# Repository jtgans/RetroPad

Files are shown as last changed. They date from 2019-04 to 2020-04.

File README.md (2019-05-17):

# RetroPad v2.0

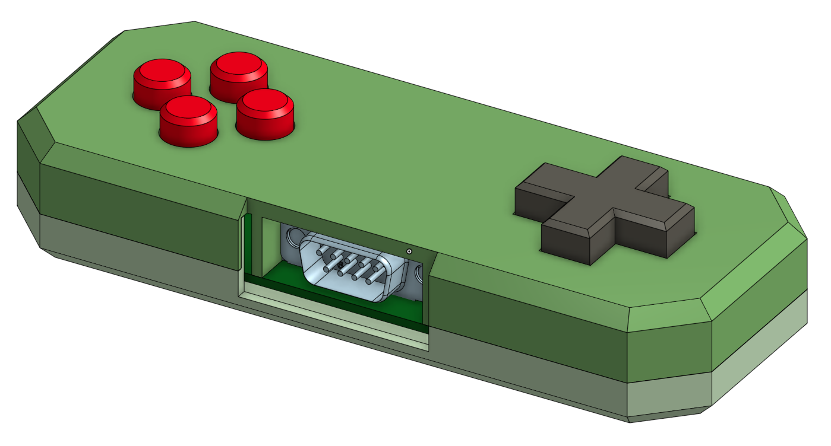
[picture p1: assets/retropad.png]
RetroPad Mechanical Model


## What is this?

This is an open source Commodore compatible gamepad similar in design to a
Genesis or NES gamepad, but designed specifically for the Commodore and Atari
8-bit machines prior to the Amigas.

This project is part of the [Nybbles and Bytes Commodore 128D programming
series](http://youtube.com/nybblesandbytes).

## Why make this?

The author needed a joystick for her YouTube project, [Nybbles and
Bytes](http://youtube.com/nybblesandbytes) and felt that joysticks were too
imprecise, troublesome, and wanted something more accessible. Gamepads fit the
bill, but Master System and Genesis controllers used the wrong electricals and
could cause damage to her systems.

## Which computers is this compatible with?

The author has tested the initial prototype with a Commodore 128D, but
electrically RetroPad should be compatible with any machines that support
floating logic level inputs that are expected to be shorted to ground when the
switches are closed (open-drain configuration, similar to I2C). This basically
means it should theoretically work on the following machines:

  - Commodore VIC-20
  - Commodore 64
  - Commodore 128, 128D, 128DCR, etc.
  - Atari 2600, 7800, etc.
  - Atari ST*

## How was this made?

The schematics were put together using KiCad 5.0 on a Mac. This should be
cross-compatible with any other platform KiCad 5.0 runs on. The author used the
[DigiKey KiCad Libraries](https://github.com/Digi-Key/digikey-kicad-library) to
simplify footprint and symbol selection, so you'll want to download those and
set them up globally. They were not included in this project repository as
project-specific since that would effectively constitute a fork or
redistribution which would then require their licensing. Plus, the project
wouldn't get any updated footprints.

The STL files and models of the casing were designed publicly using the
parametric modelling tool, OnShape. FreeCAD was originally considered, but
unfortunately it's been too unstable for the author to use thus far.

You can get to the RetroPad Shell
project
[in OnShape here](https://cad.onshape.com/documents/0ce2d4035447341de67353ed/w/eda42658079851fc0d119e48/e/4d807dce885e1d6fdc5af67c).

Search for "RetroPad" in the public models archive and you can get the source
models straight from there. For folks preferring to use a different modelling
program, the STL files are also available with the schematics in this
repository under
the [case/ directory](https://github.com/jtgans/RetroPad/tree/master/case).

The "RetroPad.step" file is actually just the 3D rendering of the PCBA.

## Where is the BOM?

The BOM is very very simple at the moment, basically only using Omron B3F-1000
tactile switches straight from Digikey. Any 8mm pitch tactile switch with a
similar profile to the B3F-1000 should work.

The connection to the computer is made using a 9-pin D-Sub connector. Any
straight-through female to female 9-pin serial cable should work, supposing the
housing allows for it.

Assembly is super easy since it's all through hole parts and two very large 0608
SMD resistors.

The generated BOM is available in the CSV file in this repository, but an actual
BOM ordered by the author is available in the digikey.csv file.

## How should I fab the PCB?

The author prefers to use OSHPark as the PCB fab house of choice, though with
some finagling you could easily adapt to other providers such as PCBWay or
others.

The original PCB is
available [on oshpark here](https://oshpark.com/shared_projects/t22Mpv2t).

## How should I fab the case?

The author used her Prusa i3 Mk3s FDM 3D printer with a 0.2mm layer height and
no support to print out the case. The model requires a high degree of precision
in the printer, with a 0.1mm tolerance between the fire and jump buttons and the
top half of the shell. The D-Pad area requires at least 0.5mm tolerance. You may
have to file the parts down a small amount, depending on the resolution and
precision of your printer.

Note that the case is designed to hold together using friction, so no fasteners
are necessary. Also note that in the v1.1 design, there's not quite enough of a
cutout for the cable strain relief to fit, so it may bow out a small amount.

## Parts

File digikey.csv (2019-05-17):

Manufacturer Part Number | Manufacturer | Digi-Key Part Number | Customer Reference | Reference Designator | Packaging | Part Status | Quantity | Unit Price | Extended Price | Quantity Available | Mfg Std Lead Time | Description | RoHS Status | Lead Free Status | REACH Status | US Tariff Status
DLS1XP5AK40X | Conec | 626-1953-ND | 9-pin Connector |  | Box | Active | 1 | 1.31000 | $1.31 | 1881 | 12 Weeks | CONN D-SUB PLUG 9 POS R/A SOLDER | RoHS Compliant | Lead free | REACH Unaffected
B3F-1000 | Omron Electronics Inc-EMC Div | SW400-ND | Buttons |  | Bulk | Active | 8 | 0.27000 | $2.16 | 38557 | 13 Weeks | SWITCH TACTILE SPST-NO 0.05A 24V | RoHS Compliant | Lead free | Not Available
30-9506-77 | Cinch Connectivity Solutions AIM-Cambridge | 367-1145-ND | 9-pin straight through cable |  | Bulk | Active | 1 | 4.90000 | $4.90 | 144 | 11 Weeks | CABLE ASSY DB09 SHLD BEIGE 1.83M | RoHS Compliant | Lead free | Not Available | Tariff Applied
RR1220P-331-D | Susumu | RR12P330DCT-ND |  |  | Cut Tape (CT) | Active | 2 | 0.11000 | $0.22 | 154344 | 16 Weeks | RES SMD 330 OHM 0.5% 1/10W 0805 | RoHS Compliant | Lead free | Not Available | Tariff Applied

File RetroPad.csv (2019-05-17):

Ref | Value | Footprint | Datasheet | Manufacturer | Vendor
J1 | 5747840-3 | digikey-footprints:DSUB-9_Jack_5747840-3 | https://www.te.com/commerce/DocumentDelivery/DDEController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 | TE Connectivity AMP Connectors
R1 | 330 | Resistor_SMD:R_0805_2012Metric_Pad1.15x1.40mm_HandSolder | ~
R2 | 330 | Resistor_SMD:R_0805_2012Metric_Pad1.15x1.40mm_HandSolder | ~
S1 | FIRE | digikey-footprints:Switch_Tactile_THT_B3F-1xxx | https://omronfs.omron.com/en_US/ecb/products/pdf/en-b3f.pdf | Omron Electronics Inc-EMC Div
S2 | DOWN | digikey-footprints:Switch_Tactile_THT_B3F-1xxx | https://omronfs.omron.com/en_US/ecb/products/pdf/en-b3f.pdf | Omron Electronics Inc-EMC Div
S3 | LEFT | digikey-footprints:Switch_Tactile_THT_B3F-1xxx | https://omronfs.omron.com/en_US/ecb/products/pdf/en-b3f.pdf | Omron Electronics Inc-EMC Div
S4 | RIGHT | digikey-footprints:Switch_Tactile_THT_B3F-1xxx | https://omronfs.omron.com/en_US/ecb/products/pdf/en-b3f.pdf | Omron Electronics Inc-EMC Div
S5 | UP | digikey-footprints:Switch_Tactile_THT_B3F-1xxx | https://omronfs.omron.com/en_US/ecb/products/pdf/en-b3f.pdf | Omron Electronics Inc-EMC Div
S6 | FIRE2 | digikey-footprints:Switch_Tactile_THT_B3F-1xxx | https://omronfs.omron.com/en_US/ecb/products/pdf/en-b3f.pdf | Omron Electronics Inc-EMC Div
S7 | JUMP | digikey-footprints:Switch_Tactile_THT_B3F-1xxx | https://omronfs.omron.com/en_US/ecb/products/pdf/en-b3f.pdf | Omron Electronics Inc-EMC Div
S8 | FIRE3 | digikey-footprints:Switch_Tactile_THT_B3F-1xxx | https://omronfs.omron.com/en_US/ecb/products/pdf/en-b3f.pdf | Omron Electronics Inc-EMC Div

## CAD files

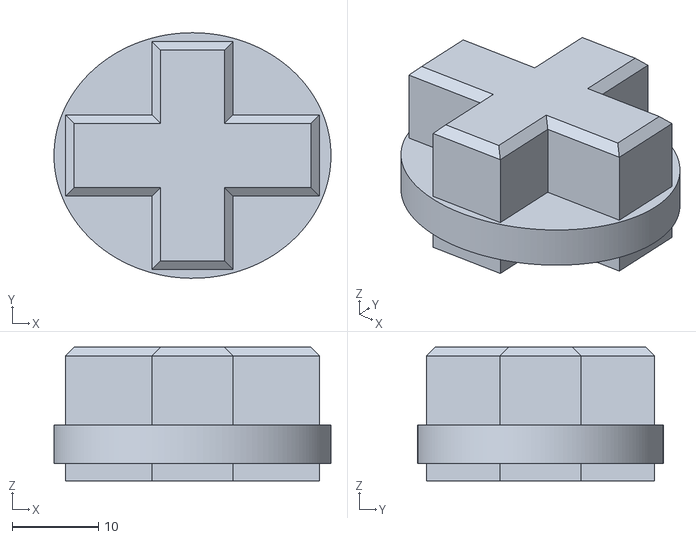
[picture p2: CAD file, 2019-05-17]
case/RetroPad - D-Pad.stl
32.1 x 28.4 x 15.5

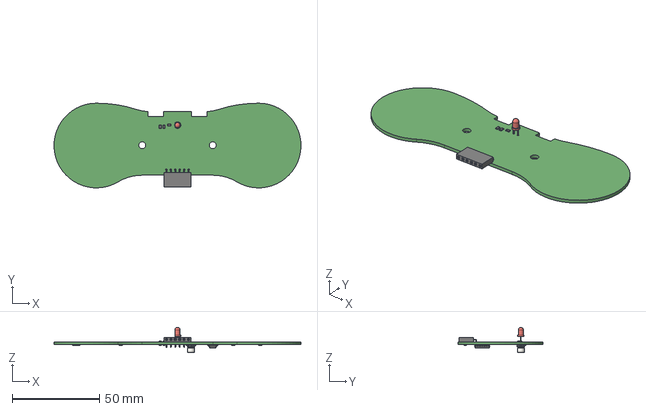
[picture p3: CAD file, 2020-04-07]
RetroPad.step
141.5 x 48.5 x 14.5 mm

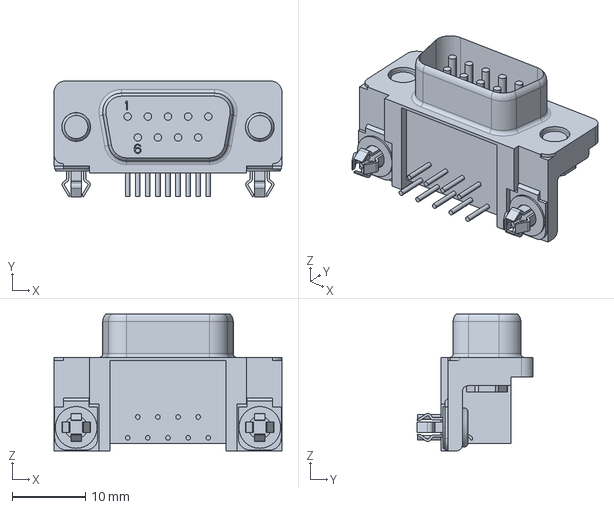
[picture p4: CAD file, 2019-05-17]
c-5747840-3-d-3d.stp
31.0 x 15.8 x 18.6 mm

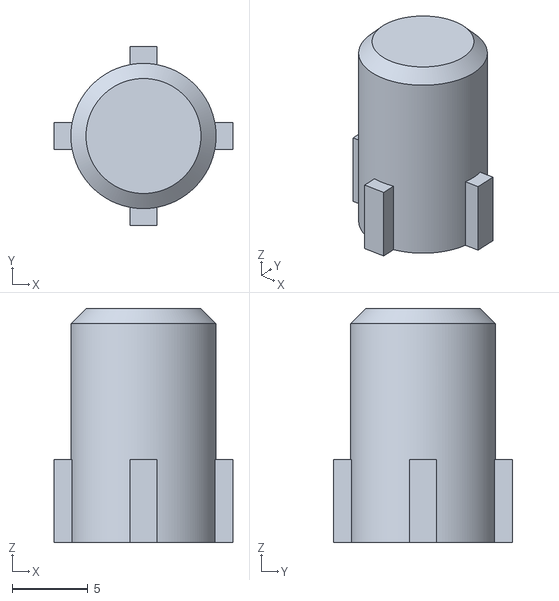
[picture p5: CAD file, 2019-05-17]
case/RetroPad - Button.stl
11.8 x 11.8 x 15.5

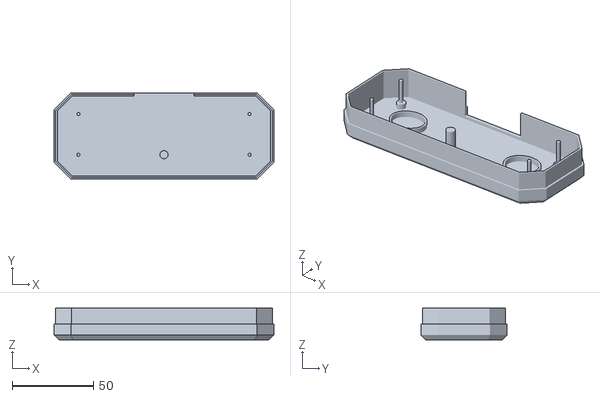
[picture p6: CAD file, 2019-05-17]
case/RetroPad - Bottom Shell.stl
135.0 x 53.0 x 19.4

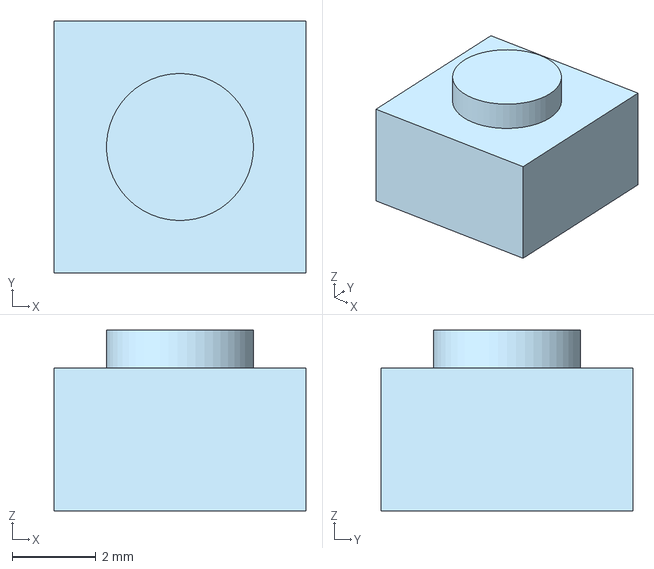
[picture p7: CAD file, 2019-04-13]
Omron B3F-1000.step
6.00 x 6.00 x 4.30 mm

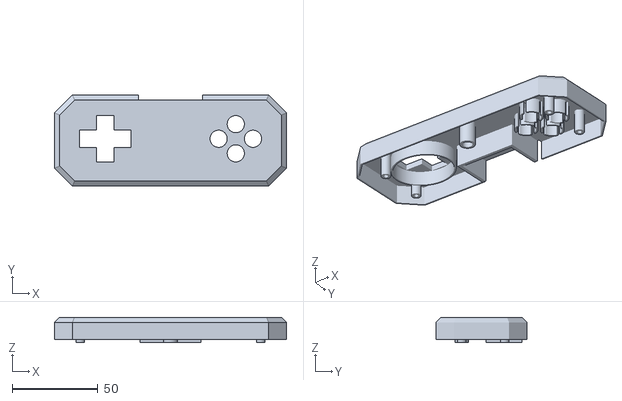
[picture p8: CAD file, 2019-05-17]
case/RetroPad - Top Shell.stl
135.0 x 53.0 x 14.8

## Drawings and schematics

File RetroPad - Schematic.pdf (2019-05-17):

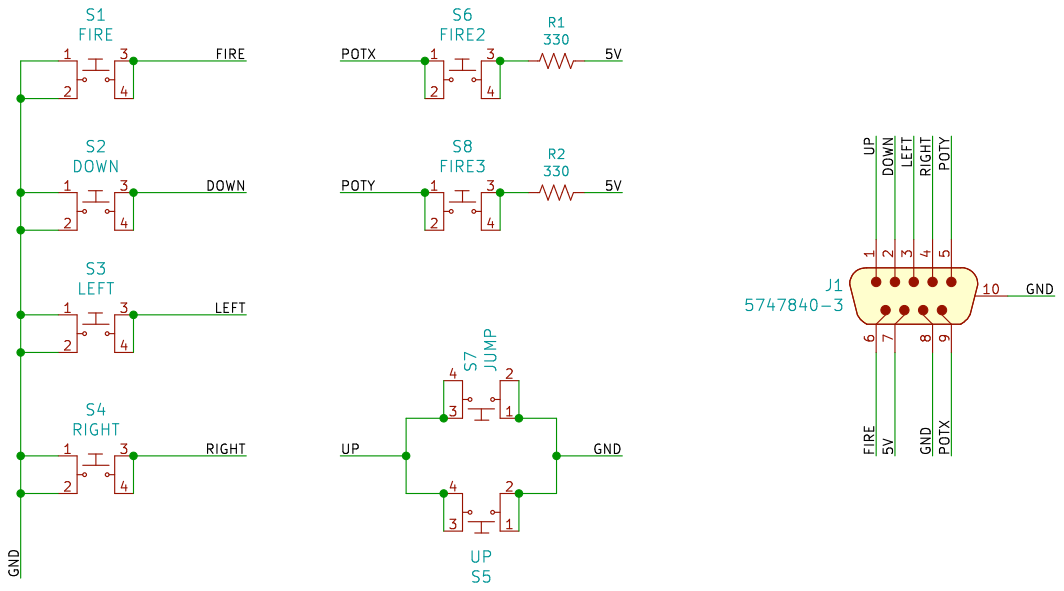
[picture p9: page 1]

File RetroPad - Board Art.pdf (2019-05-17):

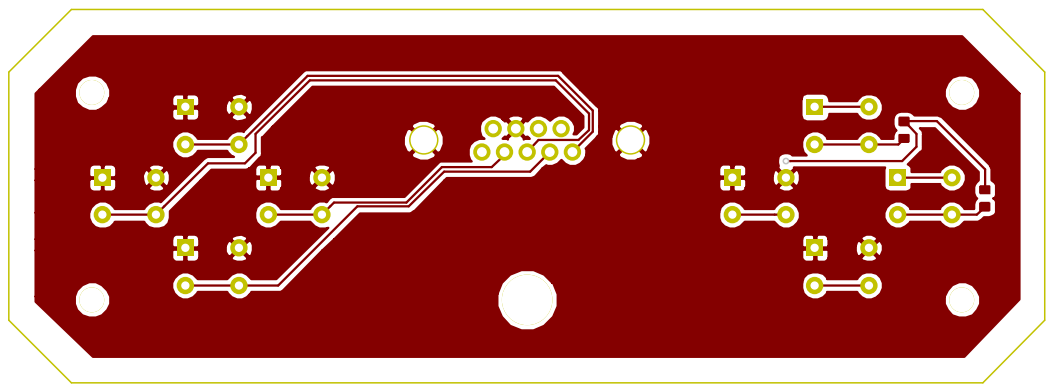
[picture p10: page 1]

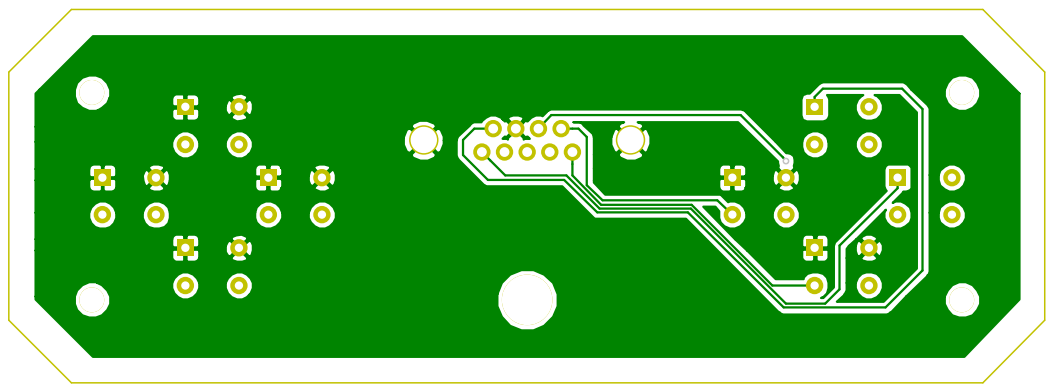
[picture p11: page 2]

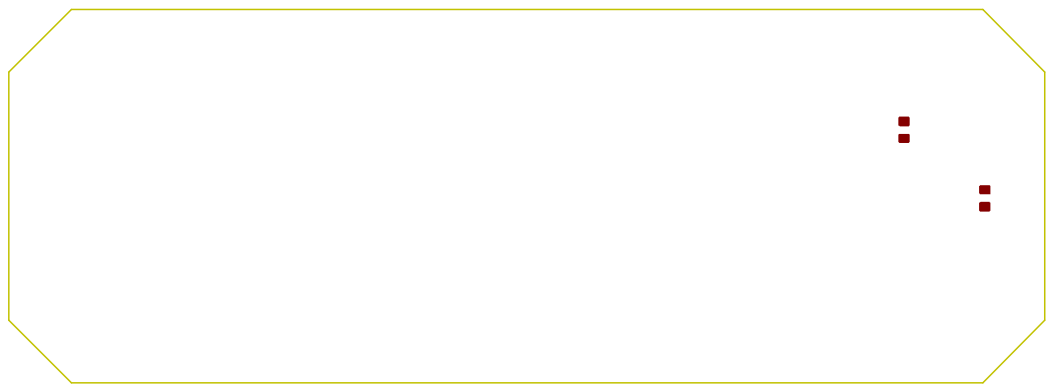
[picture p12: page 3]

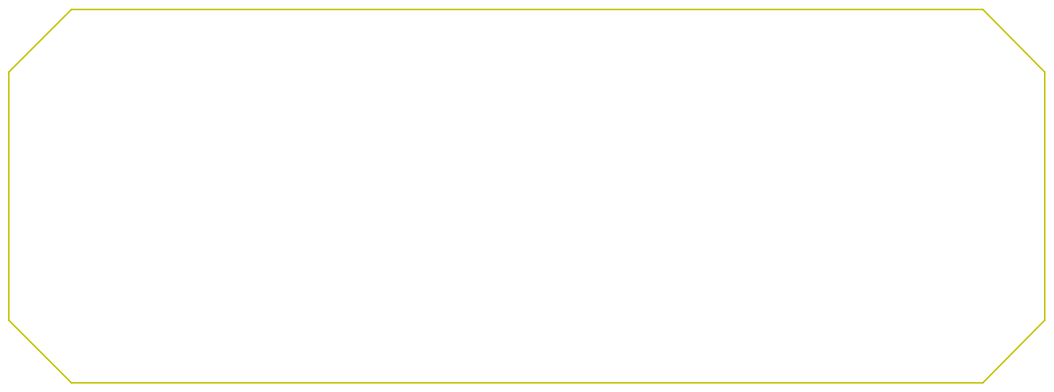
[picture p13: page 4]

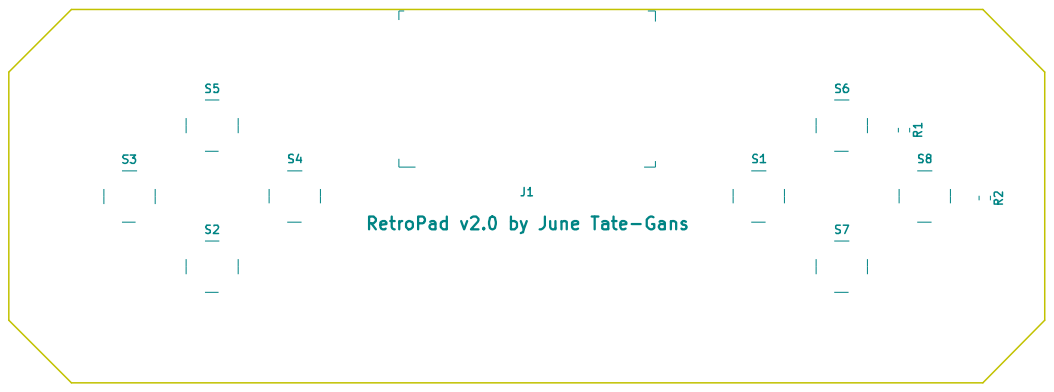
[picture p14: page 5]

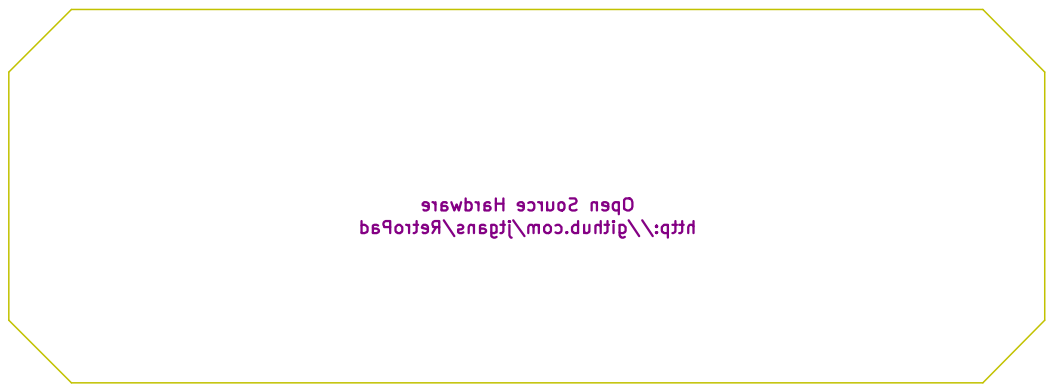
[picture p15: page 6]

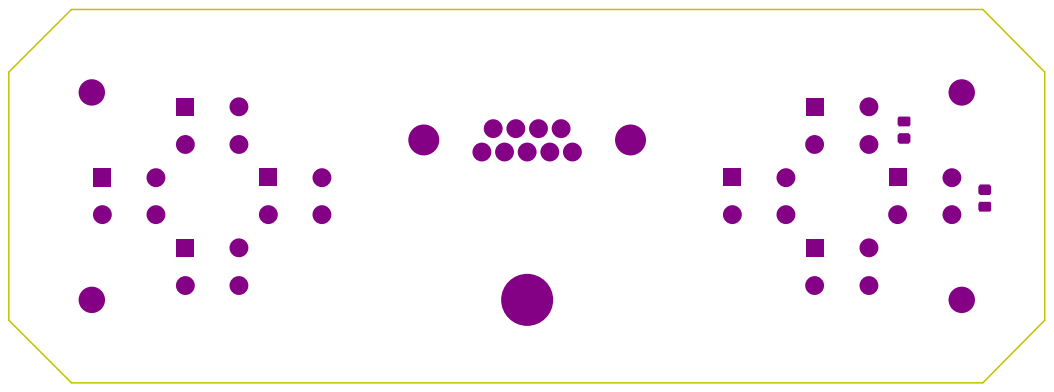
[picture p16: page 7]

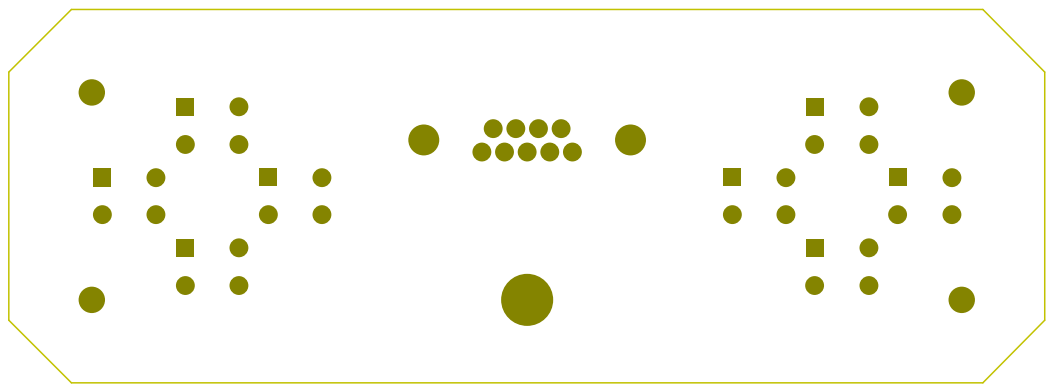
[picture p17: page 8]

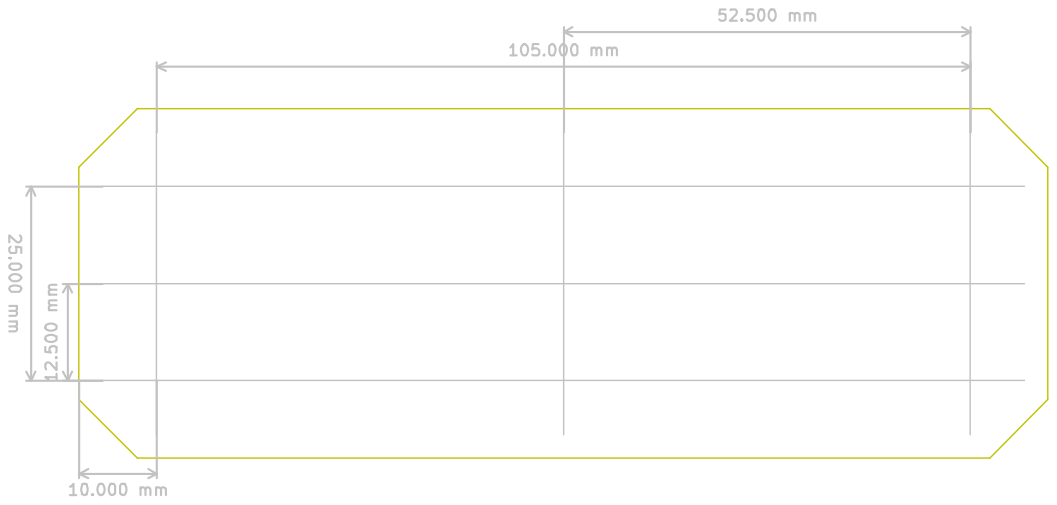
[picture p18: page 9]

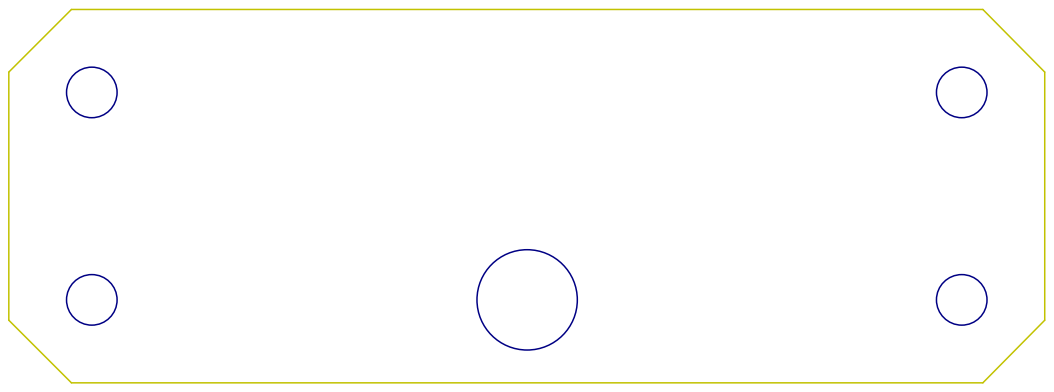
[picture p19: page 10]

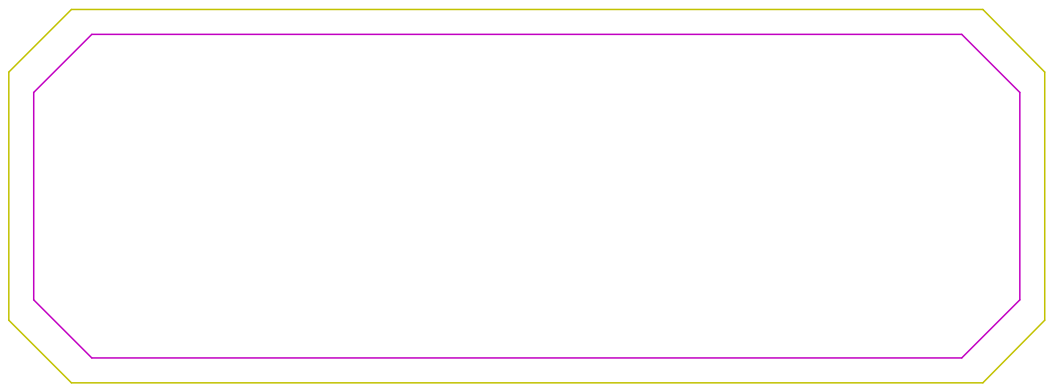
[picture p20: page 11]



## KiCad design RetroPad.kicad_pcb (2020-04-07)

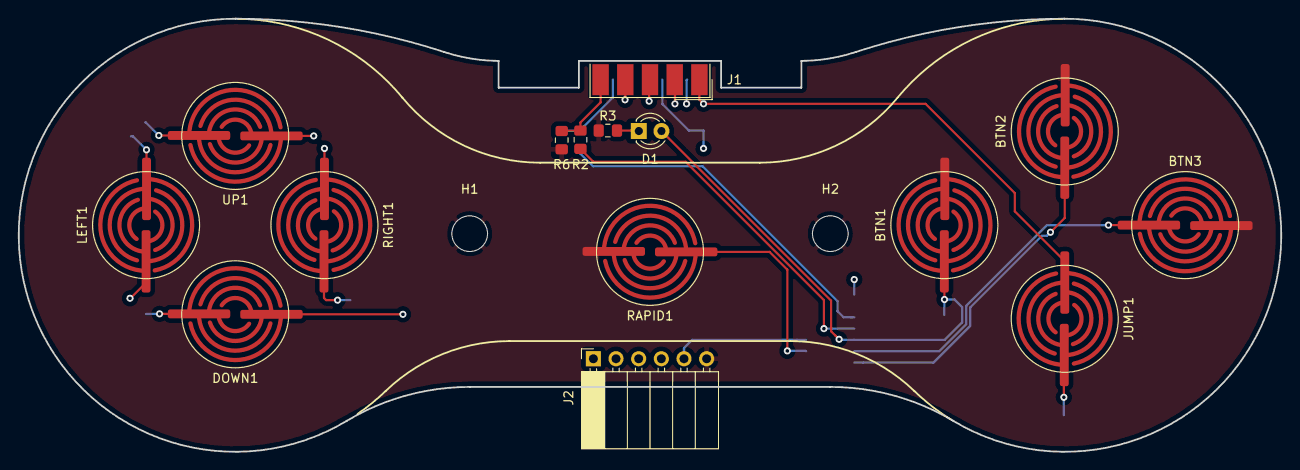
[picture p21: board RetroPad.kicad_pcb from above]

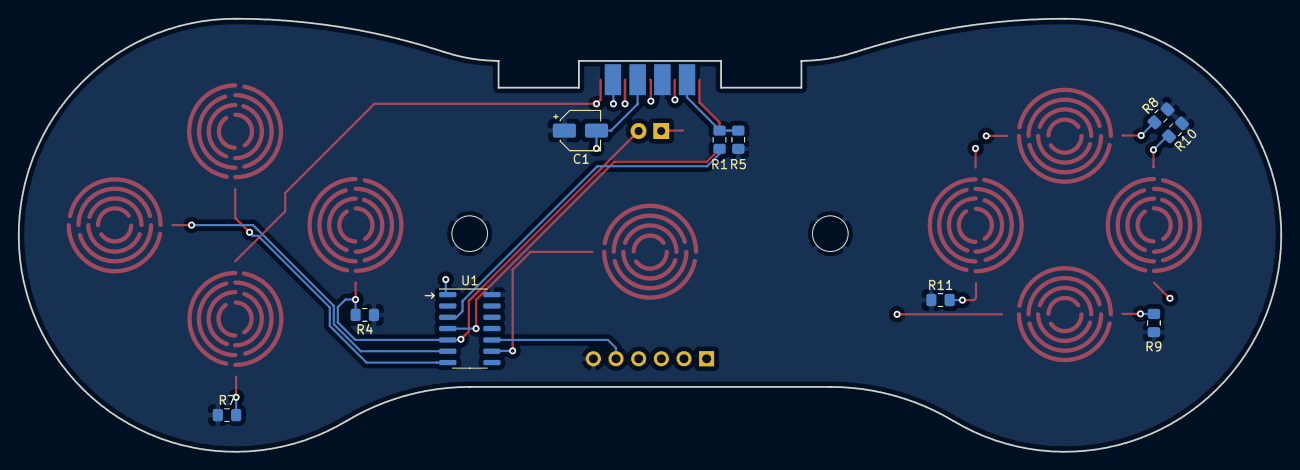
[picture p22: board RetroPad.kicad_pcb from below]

Board: 4 copper layers, 141.6 x 48.6 mm, 27 parts (10 on the bottom side), 21 nets.

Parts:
BTN1: BTN1; Silicone_Membrane_Pad_11mm_(7.5mm)
BTN2: BTN2; Silicone_Membrane_Pad_11mm_(7.5mm)
BTN3: BTN3; Silicone_Membrane_Pad_11mm_(7.5mm)
C1: 0.1uF; CP_Elec_4x4.5
D1: RAPID; LED_D3.0mm
DOWN1: DOWN; Silicone_Membrane_Pad_11mm_(7.5mm)
H1, H2: MountingHole; MountingHole_4mm
J1: DB9_Male; DSUB-9_Male_EdgeMount_P2.77mm
J2: UPDI; PinSocket_1x06_P2.54mm_Horizontal
JUMP1: JUMP; Silicone_Membrane_Pad_11mm_(7.5mm)
LEFT1: LEFT; Silicone_Membrane_Pad_11mm_(7.5mm)
R1, R2, R4, R5, R6: 1K; R_0805_2012Metric_Pad1.15x1.40mm_HandSolder
R3: 330; R_0805_2012Metric_Pad1.15x1.40mm_HandSolder
R7, R8, R9, R10, R11: 0; R_0805_2012Metric_Pad1.15x1.40mm_HandSolder
RAPID1: RAPID; Silicone_Membrane_Pad_11mm_(7.5mm)
RIGHT1: RIGHT; Silicone_Membrane_Pad_11mm_(7.5mm)
U1: ATtiny814-SS; SOIC-14_3.9x8.7mm_P1.27mm
UP1: UP; Silicone_Membrane_Pad_11mm_(7.5mm)

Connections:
+5V: C1.2, J1.7, J2.4, U1.1
/BTN2: BTN2.2, U1.7
/BTN3: BTN3.2, U1.6
/DOWN: DOWN1.2, J1.2
/FIRE: BTN1.2, D1.2, J1.6, R4.2, U1.5
/LEFT: J1.3, LEFT1.2
/OUT_BTN2: R2.2, U1.4
/OUT_BTN3: R1.2, U1.3
/POTX: J1.9, R1.1, R5.2
/POTY: J1.5, R2.1, R6.2
/RAPID: RAPID1.2, U1.9
/RESET: J2.5, U1.10
/RIGHT: J1.4, RIGHT1.2
/UP: J1.1, JUMP1.2, UP1.2
GND: BTN1.1, BTN2.1, BTN3.1, C1.1, H1.1, H2.1, J1.8, J2.6, R3.1, R4.1, R5.1, R6.1, R7.1, R8.1, R9.1, R10.1, R11.1, RAPID1.1, U1.14
unnamed: D1.1, R3.2
unnamed: DOWN1.1, R9.2
unnamed: JUMP1.1, R7.2
unnamed: LEFT1.1, R10.2
unnamed: R8.2, UP1.1
unnamed: R11.2, RIGHT1.1

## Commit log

2019-04-13 Initial commit for RetroPad v1.1.
    [CK Switches JS202011SCQN.step, Omron B3F-1000.step, RetroPad - Bottom Shell.stl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]
2019-04-19 pcb: Major revision to mechanicals
    This is a near total redesign of the RetroPad. Electrically it should be
    identical, aside from two additional buttons. Major features planned are:
    - Two additional fire buttons using POTX and POTY for games that support it.
    - Migrates from raw-through hole wiring to a proper male 9-pin D-Sub
    connector. This should be significantly more robust.
    - Mechanical redesign of the positioning for the buttons and D-pad.
    [RetroPad.csv, RetroPad.kicad_pcb, RetroPad.sch]
2019-04-19 docs: Update the README and add a Digikey BOM
    [digikey.csv]
2019-04-19 pcb: Add 3D models for the FIRE2 and FIRE3 buttons
    [RetroPad.kicad_pcb]
2019-04-19 readme: Update with information about libraries
    This project uses the DigiKey libraries for KiCad to simplify things, so we
    should mention that to folks beforehand.
2019-04-19 pcb: Refill the copper pours
    [RetroPad.kicad_pcb]
2019-04-19 readme: Update with information about libraries
    (cherry picked from commit 3f0ea1ff78b1fd4a1acff8641a87dd14f6e8ecf3)
    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
2019-04-19 models: Remove the CK Switches 3D model since it's unused
    [CK Switches JS202011SCQN.step]
2019-04-19 models: Remove the CK Switches 3D model since it's unused
    (cherry picked from commit a524397730d8e2f880d0adf93546dc6aa7588099)
    [CK Switches JS202011SCQN.step]
2019-04-20 bom: Unify the BOM CSV so it renders cleanly
    [RetroPad.csv]
2019-04-20 step: Regenerate for v2.0 with the D-Sub connector in place
    [RetroPad.kicad_pcb, RetroPad.step, c-5747840-3-d-3d.stp]
2019-04-20 case: Update the case to the new design
    This brings in all the STL files from the new design as well as a pre-rendered
    image of the new case.
    [RetroPad - Bottom Shell.stl, RetroPad - Button.stl, RetroPad - D-Pad.stl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]
2019-04-27 artifacts: Generate PDFs of the current schematic and board art
2019-04-27 kicad: Update project file
    This includes additional metadata about the schematic editor
    after printing out the PDF of the RetroPad schematic.
2019-05-17 case: Update the STL files and pre-rendered image
    [RetroPad - Bottom Shell.stl, RetroPad - Button.stl, RetroPad - D-Pad.stl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]
2020-04-07 Import of the new RetroPad v3.
    [RetroPad.kicad_pcb, RetroPad.sch]
2020-04-07 Fixed board outline.
    [RetroPad.kicad_pcb, RetroPad.step]
